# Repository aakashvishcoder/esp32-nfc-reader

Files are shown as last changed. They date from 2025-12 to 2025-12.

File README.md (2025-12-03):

# ESP32 NFC Reader

This is my very own prototype of an NFC Reader, built using the ESP32 microcontroller! It’s a compact, wireless module designed to read and interact with NFC tags and cards. This board has several unique features and components (as listed below), and demonstrates how the ESP32 can be paired with an NFC front‑end chip to enable secure communication.

# Features:
- ESP32 microcontroller
- NFC transceiver chip
- PCB antenna
- Power management
- Interfaces
- Firmware support
- Form factor

# How to Use
Plug in a USB cable into the receptacle! Install the ESP32IDE for configuration of the firmware.

# Images






# BOM
## esp32-nfc-reader BOM

| Item | Description | Qty | Product link | Price w/ Tax ($) | Running Total |
|---|---|-----|---|---|---|
| Antenna | Antenna loop (Coilcraft MA5532-AE footprint) | 1 | [link](https://jlcpcb.com/) | $0.80 | $0.80 |
| Buzzer | 15×7.5 mm buzzer (THT) | 1 | [link](https://jlcpcb.com/partdetail/Jiangsu_HuanengElec-HND2319/C2878) | $1.20 | $2.00 |
| Capacitor | 0.1uF 0402 | 4 | [link](https://jlcpcb.com/partdetail/SamsungElectro-CL05B104KO5NNNC/C1525) | $0.40 | $2.40 |
| Capacitor | 47uF (closest available) | 1 | [link](https://jlcpcb.com/partdetail/DMBJ-RVT2A47M0607/C970653) | $0.50 | $2.90 |
| Capacitor | 1uF 0402 | 3 | [link](https://jlcpcb.com/partdetail/SamsungElectro-CL05A105KA5NQNC/C52923) | $0.12 | $3.02 |
| Capacitor | 4.7uF 0402 | 1 | [link](https://jlcpcb.com/partdetail/SamsungElectro-CL05A475MP5NRNC/C2835559) | $0.20 | $3.22 |
| Capacitor | 220pF 0402 | 1 | [link](https://jlcpcb.com/partdetail/YAGEO-CC0402KRX7R9BB221/C39122) | $0.08 | $3.30 |
| Capacitor | 100pF C0G 0402 | 1 | [link](https://jlcpcb.com/partdetail/YAGEO-CC0402JRNPO9BN101/C1546) | $0.08 | $3.38 |
| Capacitor | 10uF 0402 | 1 | [link](https://jlcpcb.com/partdetail/SamsungElectro-CL05A106MQ5NUNC/C15525) | $0.36 | $3.74 |
| Capacitor | 100nF 0402 | 1 | [link](https://jlcpcb.com/partdetail/SamsungElectro-CL05B104KO5NNNC/C1525) | $0.10 | $3.84 |
| Capacitor | 15pF NP0 0402 | 2 | [link](https://jlcpcb.com/partdetail/YAGEO-CC0402JRNPO9BN150/C1547) | $0.16 | $4.00 |
| Diode | Schottky 0402 | 1 | [link](https://jlcpcb.com/partdetail/onsemi-NSR05F40NXT5G/C146713) | $0.12 | $4.12 |
| Diode | Signal diode 0402 (closest) | 1 | [link](https://jlcpcb.com/partdetail/MicrodiodeElectronics-1N4148WS/C81598) | $0.10 | $4.22 |
| LED | WS2812B 5050 | 1 | [link](https://jlcpcb.com/partdetail/Worldsemi-WS2812B_BT/C2761795) | $0.30 | $4.52 |
| TVS diode | SMA 3.3V ESD/Surge | 1 | [link](https://jlcpcb.com/partdetail/TECHPUBLIC-TVS3V3L4U/C28642315) | $0.20 | $4.72 |
| Ferrite bead | 0402 | 1 | [link](https://jlcpcb.com/partdetail/Sunlord-SDCL1005C4N7STDF/C13595) | $0.20 | $4.92 |
| USB receptacle | USB‑C 16P (USB2.0) | 1 | [link](https://jlcpcb.com/partdetail/Korean_HropartsElec-TYPE_C_31_M12/C165948) | $1.50 | $6.42 |
| Header | 1×2 pin header 1.00 mm | 1 | [link](https://jlcpcb.com/partdetail/hanxia-HX_PZ1_27_1x2P_TPYQ/C41375972) | $0.05 | $6.47 |
| Header | 1×8 pin header 1.00 mm | 1 | [link](https://jlcpcb.com/partdetail/Kinghelm-KH_1_27PH180_1X8P_L72/C2938403) | $0.20 | $6.67 |
| Relay | Finder 34.51 SPDT (THT) | 1 | [link](https://jlcpcb.com/partdetail/Finder-34_51_7_0120010/C5512438) | $2.50 | $9.17 |
| Inductor | 4.7uH (closest SMD) | 1 | [link](https://jlcpcb.com/partdetail/CENKER-CKST0402_4_7uHM/C3002596) | $0.20 | $9.37 |
| Transistor | PMOS SOT‑23 (closest) | 1 | [link](https://jlcpcb.com/partdetail/JiangsuChangjingElec-SSM3J332R/C8548) | $0.15 | $9.52 |
| Transistor | NMOS SOT‑23 (2N7002) | 1 | [link](https://jlcpcb.com/partdetail/JiangsuChangjingElec-2N7002/C8545) | $0.15 | $9.67 |
| Resistor | 5.1k 0402 | 2 | [link](https://jlcpcb.com/partdetail/UNIROYAL-0402WGF5101TCE/C25905) | $0.04 | $9.71 |
| Resistor | 10k 0402 | 5 | [link](https://jlcpcb.com/partdetail/UNIROYAL-0402WGF1002TCE/C25804) | $0.55 | $10.26 |
| Resistor | 100k 0402 | 3 | [link](https://jlcpcb.com/partdetail/UNIROYAL-0402WGF1003TCE/C269673) | $0.36 | $10.62 |
| Resistor | 56k 0402 | 1 | [link](https://jlcpcb.com/partdetail/UNIROYAL-0402WGF5602TCE/C25796) | $0.12 | $10.74 |
| Resistor | 1.8k 0402 | 1 | [link](https://jlcpcb.com/partdetail/UNIROYAL-0105WHF1801TDE/C560335) | $0.10 | $10.84 |
| Resistor | 330 0402 | 1 | [link](https://jlcpcb.com/partdetail/UNIROYAL-0105WHF3300TDE/C560354) | $0.07 | $10.91 |
| Resistor | 220 0402 | 1 | [link](https://jlcpcb.com/partdetail/UNIROYAL-0105WHF2200TDE/C560342) | $0.07 | $10.98 |
| Switch | Tactile button (PTS636‑style) | 1 | [link](https://jlcpcb.com/partdetail/XKBConnectivity-TS_1187A_B_A_B/C318884) | $0.24 | $11.22 |
| Switch | Tactile button (PTS636‑style) | 1 | [link](https://jlcpcb.com/partdetail/XKBConnectivity-TS_1187A_B_A_B/C318884) | $0.24 | $11.46 |
| Switch | Tactile button (PTS636‑style) | 1 | [link](https://jlcpcb.com/partdetail/XKBConnectivity-TS_1187A_B_A_B/C318884) | $0.24 | $11.70 |
| Module | ESP32‑S3‑WROOM‑1 | 1 | [link](https://jlcpcb.com/partdetail/Espressif-ESP32_S3_WROOM_1/C2913198) | $4.50 | $16.20 |
| IC | Buck AP63203WU | 1 | [link](https://jlcpcb.com/partdetail/DiodesInc-AP63203WU7/C780769) | $0.60 | $16.

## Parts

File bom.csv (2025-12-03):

Item | Description | Quantity | Product link | Price w/ Tax ($) | Running Total
Antenna | Antenna loop (Coilcraft MA5532-AE footprint) | 1 | https://jlcpcb.com/ | $0.80 | $0.80
Buzzer | 15×7.5 mm buzzer (THT) | 1 | https://jlcpcb.com/partdetail/Jiangsu_HuanengElec-HND2319/C2878 | $1.20 | $2.00
Capacitor | 0.1uF 0402 | 4 | https://jlcpcb.com/partdetail/SamsungElectro-CL05B104KO5NNNC/C1525 | $0.40 | $2.40
Capacitor | 47uF (closest available) | 1 | https://jlcpcb.com/partdetail/DMBJ-RVT2A47M0607/C970653 | $0.50 | $2.90
Capacitor | 1uF 0402 | 3 | https://jlcpcb.com/partdetail/SamsungElectro-CL05A105KA5NQNC/C52923 | $0.12 | $3.02
Capacitor | 4.7uF 0402 | 1 | https://jlcpcb.com/partdetail/SamsungElectro-CL05A475MP5NRNC/C2835559 | $0.20 | $3.22
Capacitor | 220pF 0402 | 1 | https://jlcpcb.com/partdetail/YAGEO-CC0402KRX7R9BB221/C39122 | $0.08 | $3.30
Capacitor | 100pF C0G 0402 | 1 | https://jlcpcb.com/partdetail/YAGEO-CC0402JRNPO9BN101/C1546 | $0.08 | $3.38
Capacitor | 10uF 0402 | 1 | https://jlcpcb.com/partdetail/SamsungElectro-CL05A106MQ5NUNC/C15525 | $0.36 | $3.74
Capacitor | 100nF 0402 | 1 | https://jlcpcb.com/partdetail/SamsungElectro-CL05B104KO5NNNC/C1525 | $0.10 | $3.84
Capacitor | 15pF NP0 0402 | 2 | https://jlcpcb.com/partdetail/YAGEO-CC0402JRNPO9BN150/C1547 | $0.16 | $4.00
Diode | Schottky 0402 | 1 | https://jlcpcb.com/partdetail/onsemi-NSR05F40NXT5G/C146713 | $0.12 | $4.12
Diode | Signal diode 0402 (closest) | 1 | https://jlcpcb.com/partdetail/MicrodiodeElectronics-1N4148WS/C81598 | $0.10 | $4.22
LED | WS2812B 5050 | 1 | https://jlcpcb.com/partdetail/Worldsemi-WS2812B_BT/C2761795 | $0.30 | $4.52
TVS diode | SMA 3.3V ESD/Surge | 1 | https://jlcpcb.com/partdetail/TECHPUBLIC-TVS3V3L4U/C28642315 | $0.20 | $4.72
Ferrite bead | 0402 | 1 | https://jlcpcb.com/partdetail/Sunlord-SDCL1005C4N7STDF/C13595 | $0.20 | $4.92
USB receptacle | USB‑C 16P (USB2.0) | 1 | https://jlcpcb.com/partdetail/Korean_HropartsElec-TYPE_C_31_M12/C165948 | $1.50 | $6.42
Header | 1×2 pin header 1.00 mm | 1 | https://jlcpcb.com/partdetail/hanxia-HX_PZ1_27_1x2P_TPYQ/C41375972 | $0.05 | $6.47
Header | 1×8 pin header 1.00 mm | 1 | https://jlcpcb.com/partdetail/Kinghelm-KH_1_27PH180_1X8P_L72/C2938403 | $0.20 | $6.67
Relay | Finder 34.51 SPDT (THT) | 1 | https://jlcpcb.com/partdetail/Finder-34_51_7_0120010/C5512438 | $2.50 | $9.17
Inductor | 4.7uH (closest SMD) | 1 | https://jlcpcb.com/partdetail/CENKER-CKST0402_4_7uHM/C3002596 | $0.20 | $9.37
Transistor | PMOS SOT‑23 (closest) | 1 | https://jlcpcb.com/partdetail/JiangsuChangjingElec-SSM3J332R/C8548 | $0.15 | $9.52
Transistor | NMOS SOT‑23 (2N7002) | 1 | https://jlcpcb.com/partdetail/JiangsuChangjingElec-2N7002/C8545 | $0.15 | $9.67
Resistor | 5.1k 0402 | 2 | https://jlcpcb.com/partdetail/UNIROYAL-0402WGF5101TCE/C25905 | $0.04 | $9.71
Resistor | 10k 0402 | 5 | https://jlcpcb.com/partdetail/UNIROYAL-0402WGF1002TCE/C25804 | $0.55 | $10.26
Resistor | 100k 0402 | 3 | https://jlcpcb.com/partdetail/UNIROYAL-0402WGF1003TCE/C269673 | $0.36 | $10.62
Resistor | 56k 0402 | 1 | https://jlcpcb.com/partdetail/UNIROYAL-0402WGF5602TCE/C25796 | $0.12 | $10.74
Resistor | 1.8k 0402 | 1 | https://jlcpcb.com/partdetail/UNIROYAL-0105WHF1801TDE/C560335 | $0.10 | $10.84
Resistor | 330 0402 | 1 | https://jlcpcb.com/partdetail/UNIROYAL-0105WHF3300TDE/C560354 | $0.07 | $10.91
Resistor | 220 0402 | 1 | https://jlcpcb.com/partdetail/UNIROYAL-0105WHF2200TDE/C560342 | $0.07 | $10.98
Switch | Tactile button (PTS636‑style) | 1 | https://jlcpcb.com/partdetail/XKBConnectivity-TS_1187A_B_A_B/C318884 | $0.24 | $11.22
Switch | Tactile button (PTS636‑style) | 1 | https://jlcpcb.com/partdetail/XKBConnectivity-TS_1187A_B_A_B/C318884 | $0.24 | $11.46
Switch | Tactile button (PTS636‑style) | 1 | https://jlcpcb.com/partdetail/XKBConnectivity-TS_1187A_B_A_B/C318884 | $0.24 | $11.70
Module | ESP32‑S3‑WROOM‑1 | 1 | https://jlcpcb.com/partdetail/Espressif-ESP32_S3_WROOM_1/C2913198 | $4.50 | $16.20
IC | Buck AP63203WU | 1 | https://jlcpcb.com/partdetail/DiodesInc-AP63203WU7/C780769 | $0.60 | $16.80
IC | NFC PN5321A3HN | 1 | https://jlcpcb.com/partdetail/NXP-PN5321A3HN_C10655/C28925 | $3.00 | $19.80
Crystal | 27.12 MHz (SMD alt.) | 1 | https://jlcpcb.com/partdetail/NDK-NX2016SA_27_12MHZ/C3008209 | $0.20 | $20.00
esp32-nfc-reader PCBA | PCBA board assembly | 1 | N/A (https://cart.jlcpcb.com/) | $43.94 | $63.94

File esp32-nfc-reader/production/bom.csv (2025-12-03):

Designator | Footprint | Quantity | Value | LCSC Part #
AE2 | Coilcraft_MA5532-AE_RFID | 1 | Antenna_Loop
BZ1 | Buzzer_15x7.5RM7.6 | 1 | Buzzer | C2878
C1,C11,C4,C6,C13 | 0402 | 5 | 100nF | C5142579
C10 | 0402 | 1 | 10uF | C466623
C12,C3,C7 | 0402 | 3 | 1uF | C7503520
C14,C15 | 0402 | 2 | 15pF | C3857558
C2 | 0402 | 1 | 47uF | C970653
C5 | 0402 | 1 | 4.7uF | C2835559
C8 | 0402 | 1 | 220pF | C39122
C9 | 0402 | 1 | 100pF | C1546
D1 | 0402 | 1 | D_Schottky | C146713
D2 | 0402 | 1 | D
D3 | LED_WS2812B_PLCC4_5.0x5.0mm_P3.2mm | 1 | WS2812B | C2761795
D4 | D_SMA | 1 | D_TVS | C571370
FB1 | 0402 | 1 | FerriteBead_Small | C32810416
J1 | USB_C_Receptacle_GCT_USB4105-xx-A_16P_TopMnt_Horizontal | 1 | USB_C_Receptacle_USB2.0_16P | C3020560
J2 | PinHeader_1x02_P1.00mm_Vertical | 1 | Conn_01x02_Pin | C41375972
J3 | PinHeader_1x08_P1.00mm_Vertical | 1 | Conn_01x08 | C2938403
K1 | Relay_SPDT_Finder_34.51_Vertical | 1 | Relay_SPDT | C5512438
L1 | 0402 | 1 | 4.7uH | C3002596
Q1 | SOT-23 | 1 | PMOS | C5273673
Q2 | SOT-23 | 1 | Q_NMOS | C239054
R1,R2 | 0402 | 2 | 5.1k | C25905
R10,R11,R12,R3,R8 | 0402 | 5 | 10k | C2889342
R13 | 0402 | 1 | 330 | C881128
R14 | 0402 | 1 | 220 | C2938403
R4,R6,R7 | 0402 | 3 | 100k | C269673
R5 | 0402 | 1 | 56k | C2889346
R9 | 0402 | 1 | 1.8k | C560335
SW1 | SW_Tactile_SPST_NO_Straight_CK_PTS636Sx25SMTRLFS | 1 | RESET | C89380
SW2 | SW_Tactile_SPST_NO_Straight_CK_PTS636Sx25SMTRLFS | 1 | BOOT | C89380
SW3 | SW_Tactile_SPST_NO_Straight_CK_PTS636Sx25SMTRLFS | 1 | USER_INPUT | C89380
U1 | ESP32-S3-WROOM-1 | 1 | ESP32-S3-WROOM-1 | C2913198
U2 | TSOT-23-6 | 1 | AP63203WU | C780769
U3 | HVQFN-40-1EP_6x6mm_P0.5mm_EP4.1x4.1mm | 1 | PN5321A3HN_C1xx | C28925
Y1 | Crystal_HC49-U-3Pin_Vertical | 1 | 27.12MHz | C5265815

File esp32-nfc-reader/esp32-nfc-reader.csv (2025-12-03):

Reference | Qty | Value | DNP | Exclude from BOM | Exclude from Board | Footprint | Datasheet | Price (USD ea.) | Total (USD)
AE2 | 1 | Antenna_Loop |  |  |  | RF_Antenna:Coilcraft_MA5532-AE_RFID | ~ | 0.80 | 0.80
BZ1 | 1 | Buzzer |  |  |  | Buzzer_Beeper:Buzzer_15x7.5RM7.6 | ~ | 1.20 | 1.20
C1,C4,C6,C11 | 4 | 0.1uF |  |  |  | Capacitor_SMD:C_0402_1005Metric | ~ | 0.10 | 0.40
C2 | 1 | 47uF |  |  |  | Capacitor_SMD:C_0402_1005Metric | ~ | 0.50 | 0.50
C3,C7,C12 | 3 | 1uF |  |  |  | Capacitor_SMD:C_0402_1005Metric | ~ | 0.04 | 0.12
C5 | 1 | 4.7uF |  |  |  | Capacitor_SMD:C_0402_1005Metric | ~ | 0.20 | 0.20
C8 | 1 | 220pF |  |  |  | Capacitor_SMD:C_0402_1005Metric | ~ | 0.08 | 0.08
C9 | 1 | 100pF |  |  |  | Capacitor_SMD:C_0402_1005Metric | ~ | 0.08 | 0.08
C10 | 1 | 10uF |  |  |  | Capacitor_SMD:C_0402_1005Metric | ~ | 0.36 | 0.36
C13 | 1 | 100nF |  |  |  | Capacitor_SMD:C_0402_1005Metric | ~ | 0.10 | 0.10
C14,C15 | 2 | 15pF |  |  |  | Capacitor_SMD:C_0402_1005Metric | ~ | 0.08 | 0.16
D1 | 1 | D_Schottky |  |  |  | Diode_SMD:D_0402_1005Metric | ~ | 0.12 | 0.12
D2 | 1 | D |  |  |  | Diode_SMD:D_0402_1005Metric | ~ | 0.10 | 0.10
D3 | 1 | WS2812B |  |  |  | LED_SMD:LED_WS2812B_PLCC4_5.0x5.0mm_P3.2mm | https://cdn-shop.adafruit.com/datasheets/WS2812B.pdf | 0.30 | 0.30
D4 | 1 | D_TVS |  |  |  | Diode_SMD:D_SMA | ~ | 0.20 | 0.20
FB1 | 1 | FerriteBead_Small |  |  |  | Inductor_SMD:L_0402_1005Metric | ~ | 0.20 | 0.20
J1 | 1 | USB_C_Receptacle_USB2.0_16P |  |  |  | Connector_USB:USB_C_Receptacle_GCT_USB4105-xx-A_16P_TopMnt_Horizontal | https://www.usb.org/sites/default/files/documents/usb_type-c.zip | 1.50 | 1.50
J2 | 1 | Conn_01x02_Pin |  |  |  | Connector_PinHeader_1.00mm:PinHeader_1x02_P1.00mm_Vertical | ~ | 0.05 | 0.05
J3 | 1 | Conn_01x08 |  |  |  | Connector_PinHeader_1.00mm:PinHeader_1x08_P1.00mm_Vertical | ~ | 0.20 | 0.20
K1 | 1 | Relay_SPDT |  |  |  | Relay_THT:Relay_SPDT_Finder_34.51_Vertical | ~ | 2.50 | 2.50
L1 | 1 | 4.7uH |  |  |  | Inductor_SMD:L_0402_1005Metric | ~ | 0.20 | 0.20
Q1 | 1 | PMOS |  |  |  | Package_TO_SOT_SMD:SOT-23 | https://ngspice.sourceforge.io/docs/ngspice-html-manual/manual.xhtml#cha_MOSFETs | 0.15 | 0.15
Q2 | 1 | Q_NMOS |  |  |  | Package_TO_SOT_SMD:SOT-23 | ~ | 0.15 | 0.15
R1,R2 | 2 | 5.1k |  |  |  | Resistor_SMD:R_0402_1005Metric | ~ | 0.02 | 0.04
R3,R8,R10,R11,R12 | 5 | 10k |  |  |  | Resistor_SMD:R_0402_1005Metric | ~ | 0.11 | 0.55
R4,R6,R7 | 3 | 100k |  |  |  | Resistor_SMD:R_0402_1005Metric | ~ | 0.12 | 0.36
R5 | 1 | 56k |  |  |  | Resistor_SMD:R_0402_1005Metric | ~ | 0.12 | 0.12
R9 | 1 | 1.8k |  |  |  | Resistor_SMD:R_0402_1005Metric | ~ | 0.10 | 0.10
R13 | 1 | 330 |  |  |  | Resistor_SMD:R_0402_1005Metric | ~ | 0.07 | 0.07
R14 | 1 | 220 |  |  |  | Resistor_SMD:R_0402_1005Metric | ~ | 0.07 | 0.07
SW1 | 1 | RESET |  |  |  | Button_Switch_SMD:SW_Tactile_SPST_NO_Straight_CK_PTS636Sx25SMTRLFS | ~ | 0.24 | 0.24
SW2 | 1 | BOOT |  |  |  | Button_Switch_SMD:SW_Tactile_SPST_NO_Straight_CK_PTS636Sx25SMTRLFS | ~ | 0.24 | 0.24
SW3 | 1 | USER_INPUT |  |  |  | Button_Switch_SMD:SW_Tactile_SPST_NO_Straight_CK_PTS636Sx25SMTRLFS | ~ | 0.24 | 0.24
U1 | 1 | ESP32-S3-WROOM-1 |  |  |  | RF_Module:ESP32-S3-WROOM-1 | https://www.espressif.com/sites/default/files/documentation/esp32-s3-wroom-1_wroom-1u_datasheet_en.pdf | 4.50 | 4.50
U2 | 1 | AP63203WU |  |  |  | Package_TO_SOT_SMD:TSOT-23-6 | https://www.diodes.com/assets/Datasheets/AP63200-AP63201-AP63203-AP63205.pdf | 0.60 | 0.60
U3 | 1 | PN5321A3HN_C1xx |  |  |  | Package_DFN_QFN:HVQFN-40-1EP_6x6mm_P0.5mm_EP4.1x4.1mm | https://www.nxp.com/docs/en/nxp/data-sheets/PN532_C1.pdf | 3.00 | 3.00
Y1 | 1 | 27.12MHz |  |  |  | Crystal:Crystal_HC49-U-3Pin_Vertical | ~ | 0.20 | 0.20

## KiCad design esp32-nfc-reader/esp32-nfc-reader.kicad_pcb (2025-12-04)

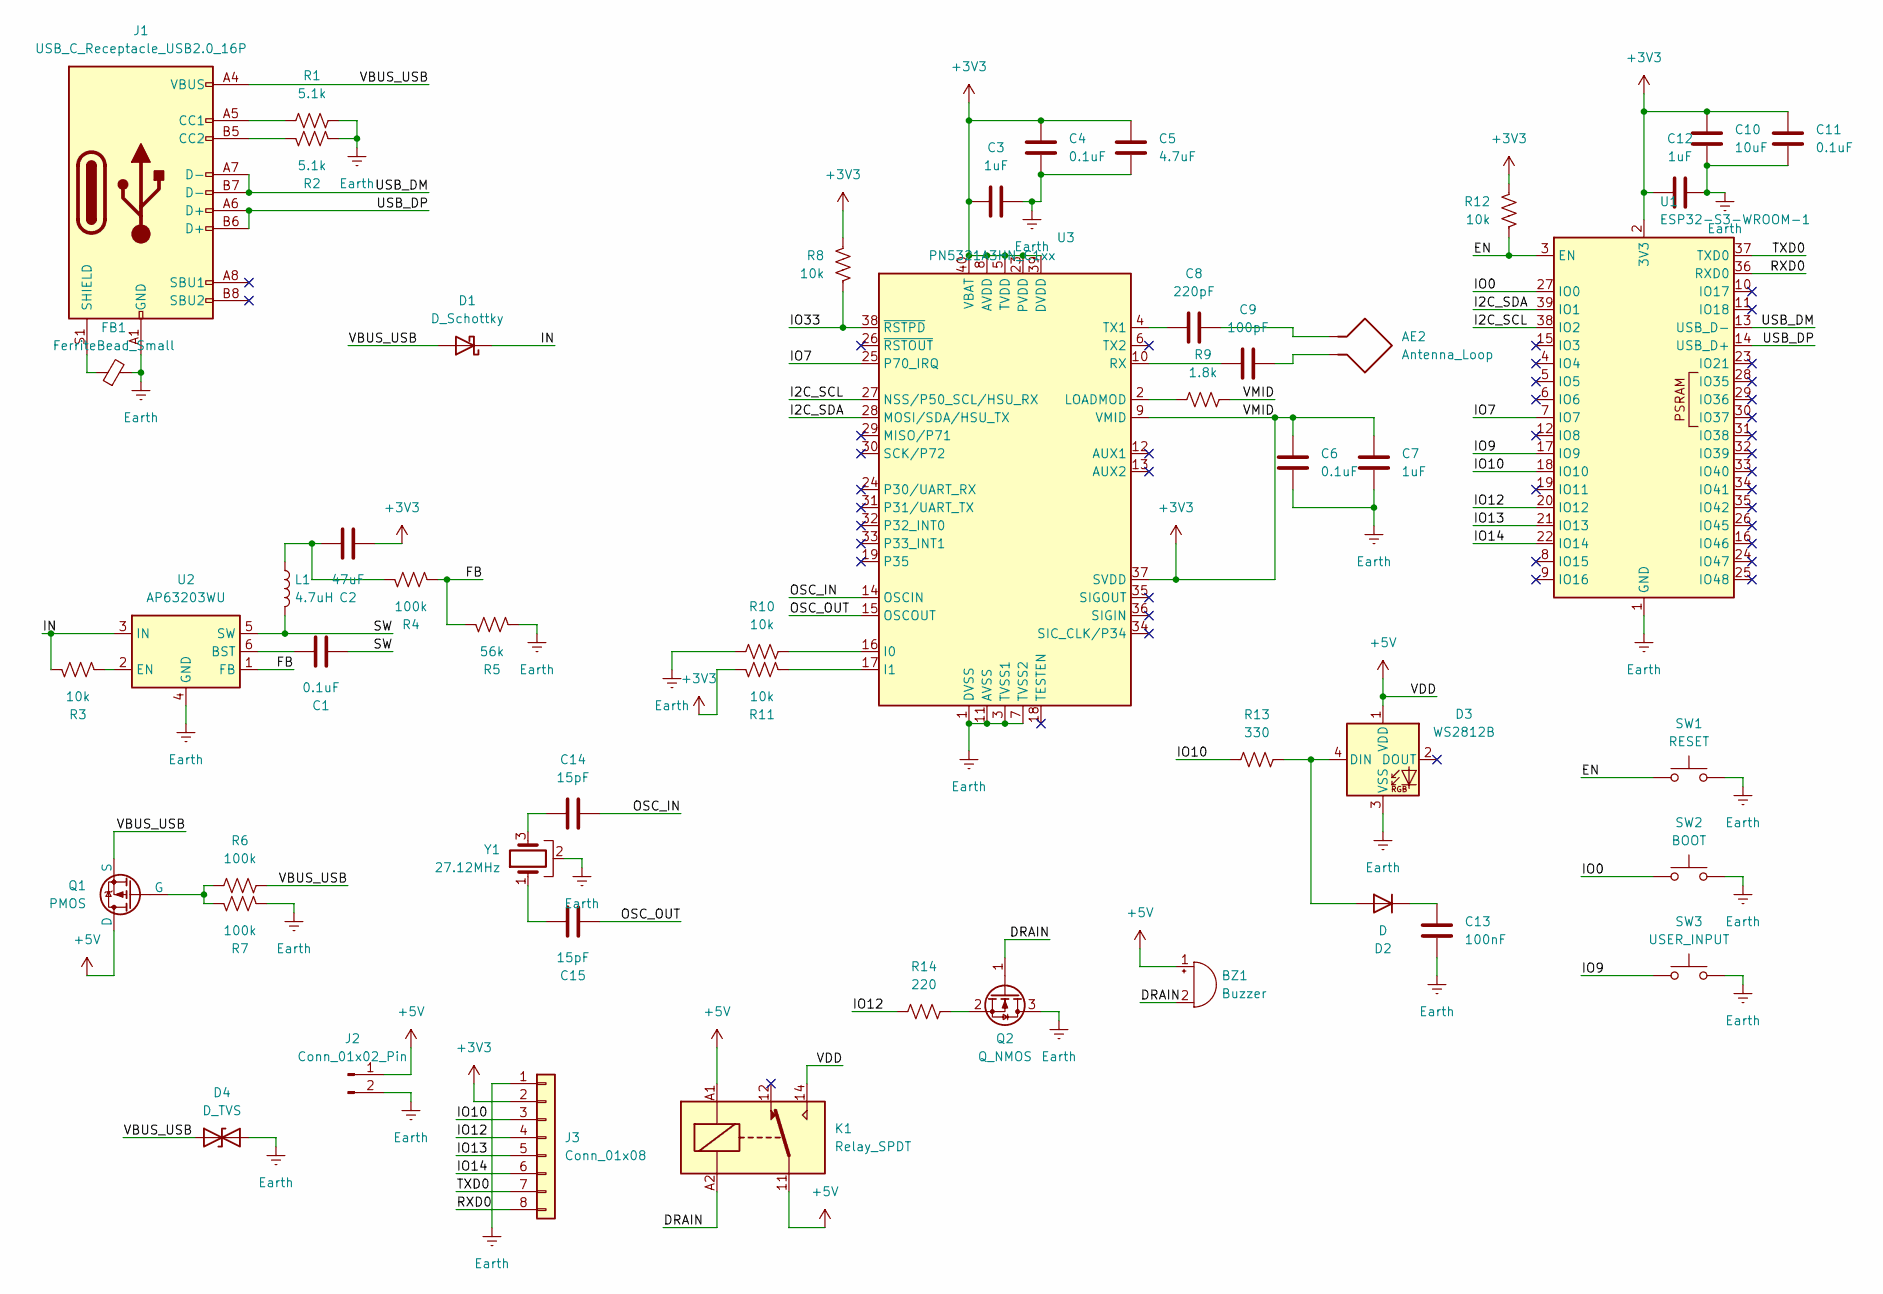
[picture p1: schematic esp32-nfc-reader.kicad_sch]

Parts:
AE2: Antenna_Loop; Coilcraft_MA5532-AE_RFID
BZ1: Buzzer; Buzzer_15x7.5RM7.6
C1, C4, C6, C11: 0.1uF; C_0402_1005Metric
C2: 47uF; C_0402_1005Metric
C3, C7, C12: 1uF; C_0402_1005Metric
C5: 4.7uF; C_0402_1005Metric
C8: 220pF; C_0402_1005Metric
C9: 100pF; C_0402_1005Metric
C10: 10uF; C_0402_1005Metric
C13: 100nF; C_0402_1005Metric
C14, C15: 15pF; C_0402_1005Metric
D1: D_Schottky; D_0402_1005Metric
D2: D; D_0402_1005Metric
D3: WS2812B; LED_WS2812B_PLCC4_5.0x5.0mm_P3.2mm
D4: D_TVS; D_SMA
FB1: FerriteBead_Small; L_0402_1005Metric
J1: USB_C_Receptacle_USB2.0_16P; USB_C_Receptacle_GCT_USB4105-xx-A_16P_TopMnt_Horizontal
J2: Conn_01x02_Pin; PinHeader_1x02_P1.00mm_Vertical
J3: Conn_01x08; PinHeader_1x08_P1.00mm_Vertical
K1: Relay_SPDT; Relay_SPDT_Finder_34.51_Vertical
L1: 4.7uH; L_0402_1005Metric
Q1: PMOS; SOT-23
Q2: Q_NMOS; SOT-23
R1, R2: 5.1k; R_0402_1005Metric
R3, R8, R10, R11, R12: 10k; R_0402_1005Metric
R4, R6, R7: 100k; R_0402_1005Metric
R5: 56k; R_0402_1005Metric
R9: 1.8k; R_0402_1005Metric
R13: 330; R_0402_1005Metric
R14: 220; R_0402_1005Metric
SW1: RESET; SW_Tactile_SPST_NO_Straight_CK_PTS636Sx25SMTRLFS
SW2: BOOT; SW_Tactile_SPST_NO_Straight_CK_PTS636Sx25SMTRLFS
SW3: USER_INPUT; SW_Tactile_SPST_NO_Straight_CK_PTS636Sx25SMTRLFS
U1: ESP32-S3-WROOM-1
U2: AP63203WU; TSOT-23-6
U3: PN5321A3HN_C1xx; HVQFN-40-1EP_6x6mm_P0.5mm_EP4.1x4.1mm
Y1: 27.12MHz; Crystal_HC49-U-3Pin_Vertical

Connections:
+3V3: C2.2, C3.1, C4.2, C5.2, C6.1, C7.1, C10.1, C11.1, C12.1, J3.2, R8.1, R9.2, R11.1, R12.1, U1.2 (3V3), U3.5 (TVDD), U3.8 (AVDD), U3.9 (VMID), U3.23 (PVDD), U3.37 (SVDD), U3.39 (DVDD), U3.40 (VBAT)
+5V: BZ1.1 (+), D3.1 (VDD), J2.1, K1.11, K1.14, K1.A1, Q1.1 (D)
/DRAIN: BZ1.2 (-), K1.A2, Q2.1 (G)
/EN: R12.2, SW1.1, U1.3 (EN)
/FB: R4.2, R5.1, U2.1 (FB)
/I2C_SCL: U1.38 (IO2), U3.27 (NSS/P50_SCL/HSU_RX)
/I2C_SDA: U1.39 (IO1), U3.28 (MOSI/SDA/HSU_TX)
/IN: D1.1 (K), R3.1, U2.3 (IN)
/IO0: SW2.1, U1.27 (IO0)
/IO7: U1.7 (IO7), U3.25 (P70_IRQ)
/IO9: SW3.1, U1.17 (IO9)
/IO10: J3.3, R13.1, U1.18 (IO10)
/IO12: J3.4, R14.1, U1.20 (IO12)
/IO13: J3.5, U1.21 (IO13)
/IO14: J3.6, U1.22 (IO14)
/IO33: R8.2, U3.38 (~RSTPD)
/OSC_IN: C14.2, U3.14 (OSCIN)
/OSC_OUT: C15.2, U3.15 (OSCOUT)
/RXD0: J3.8, U1.36 (RXD0)
/SW: C1.2, L1.2, U2.5 (SW)
/TXD0: J3.7, U1.37 (TXD0)
/USB_DM: J1.A7 (D-), J1.B7 (D-), U1.13 (USB_D-)
/USB_DP: J1.A6 (D+), J1.B6 (D+), U1.14 (USB_D+)
/VBUS_USB: D1.2 (A), D4.1 (A1), J1.A4 (VBUS), J1.A9 (VBUS), J1.B4 (VBUS), J1.B9 (VBUS), Q1.3 (S), R6.2
Earth: C3.2, C4.1, C5.1, C6.2, C7.2, C10.2, C11.2, C12.2, C13.2, D3.3 (VSS), D4.2 (A2), FB1.2, J1.A1 (GND), J1.A12 (GND), J1.B1 (GND), J1.B12 (GND), J2.2, J3.1, Q2.3 (D), R1.2, R2.2, R5.2, R7.1, R10.1, SW1.2, SW2.2, SW3.2, U1.1 (GND), U1.40 (GND), U1.41 (GND), U2.4 (GND), U3.1 (DVSS), U3.3 (TVSS1), U3.7 (TVSS2), U3.11 (AVSS), U3.41 (AVSS), Y1.2
unnamed: AE2.1, C8.2
unnamed: AE2.2, C9.1
unnamed: C2.1, L1.1, R4.1
unnamed: C14.1, Y1.3
unnamed: C15.1, Y1.1
unnamed: D2.2 (A), D3.4 (DIN), R13.2
unnamed: C13.1, D2.1 (K)
unnamed: J1.A5 (CC1), R1.1
unnamed: J1.B5 (CC2), R2.1
unnamed: FB1.1, J1.S1 (SHIELD)
unnamed: Q1.2 (G), R6.1, R7.2
unnamed: Q2.2 (S), R14.2
unnamed: C1.1, U2.6 (BST)
unnamed: R3.2, U2.2 (EN)
unnamed: R10.2, U3.16 (I0)
unnamed: R11.2, U3.17 (I1)
unnamed: R9.1, U3.2 (LOADMOD)
unnamed: C9.2, U3.10 (RX)
unnamed: C8.1, U3.4 (TX1)

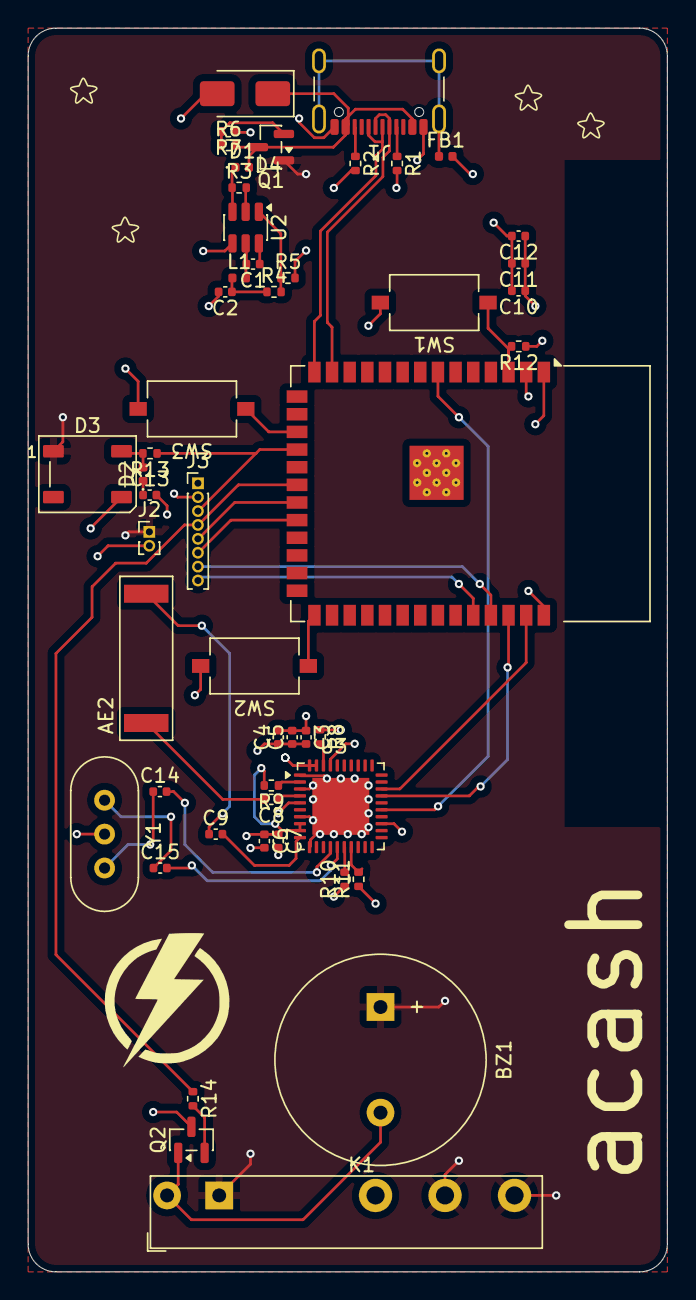
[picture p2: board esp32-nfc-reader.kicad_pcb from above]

Board: 4 copper layers, 46.0 x 89.5 mm, 50 parts (0 on the bottom side), 44 nets.

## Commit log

2025-11-29 completed pcb!
    [esp32-nfc-reader.kicad_pcb, esp32-nfc-reader.kicad_sch]
2025-11-29 Add README for ESP32 NFC Reader project
2025-11-30 Add BOM section to README
    Added a Bill of Materials (BOM) section with component details.
2025-12-01 added antenna loop
    [esp32-nfc-reader.kicad_pcb, esp32-nfc-reader.kicad_sch]
2025-12-01 Add new images and update BOM reference
2025-12-01 quick change to the pcb
    [esp32-nfc-reader.kicad_pcb]
2025-12-01 Update BOM table to include pricing information
    Added price and total cost columns to BOM table.
2025-12-03 updated bom.csv
    [esp32-nfc-reader.csv]
2025-12-03 readded the bom.csv (accidentally had it on the gitignore)
    [bom.csv, esp32-nfc-reader.csv]
2025-12-03 added a gerber file
2025-12-03 added the finished bom + added gerbers + added production + fixed some other issues
    [bom.csv, designators.csv, esp32-nfc-reader.kicad_pcb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]
2025-12-04 fixed some issues with pcb
    [esp32-nfc-reader.kicad_pcb]
